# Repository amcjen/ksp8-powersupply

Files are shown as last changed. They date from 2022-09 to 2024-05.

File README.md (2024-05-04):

# ksp8-powersupply
A replacement power supply PCB for the Kurzweil KSP8

Fbf42NQUUAAcW0R

Fbf42NQUEAM9DEA

Fbf42NTVUAAd-vw

Really simple drop-in replacement for the ancient power supply that comes with the KSP8. Included are the v9.0 compatible Eagle
.sch and .brd files, as well as the raw gerbers. The zip file has all the gerbers compressed, and you can usually upload the zip
file directly to most board houses for manufacture.

If you start hearing whining from the power supply transformer, or your unit begins resetting randomly, then it's probably the
power supply, and it's probably time to replace it.

Luckily the great people at Traco make super simple drop-in power supply modules. This board simply adds the right layout, the
proper fuses, and mimic's the power-good circuit that the KSP8 expects to see (though in reality it's likely not even necessary).

The new power supply input specs are super wide, so should be usable pretty much anywhere in the world:

Voltage input:
*90-240V VAC, 47-440 Hz*

Do of course be extremely careful with the mains power coming into this! There are several exposed leads and test points.

Regardless, most of the instructions are on the back of the board, on the silkscreen. It's reproduced here for reference:

### Jumpers
- JP1 - Tie mains gnd to 5V DC gnd (default: connected)
- JP2 - Tie /pwr_ok to voltage supervisor output (default: connected)
- JP3 - Tie /pwr_ok to 5V DC gnd (default: disconnected)

### To run with the power supervisor (default)
- Place U3 and R1
- Leave JP2 uncut
- Leave JP3 open

### To run without the power supervisor
- Exclude U3 and R1
- Cut JP2
- Solder JP3

### Required Components
- U1 - Traco TML-40105 - 5V/8A output
- U2 - Traco TML-40215 - +15V/1.3A / -15V/1.3A
- U3 - Microchip MIC810LUY power supervisor
- F1/F2 - Littelfuse 05200101Z - 1.6A slow blow 5x20mm 250V fuses
- R1 - 100k 1206 resistor

You can buy Tracos at several retailers, like Mouser and Digikey. Yes, they're pricey, but they are also medical grade, have
excellent electrical specs and clean power, and have something like a 70 year mean time between failure (MTBF). So these should
definitely outlast the device (or at least the LCD!)

One last wonderful side benefit is that these supplies seem to run pretty cool, so no need to have that loud fan running anymore.
Feel free to unplug it from the front board for a more silent studio environment.

✨ Happy music making! ✨

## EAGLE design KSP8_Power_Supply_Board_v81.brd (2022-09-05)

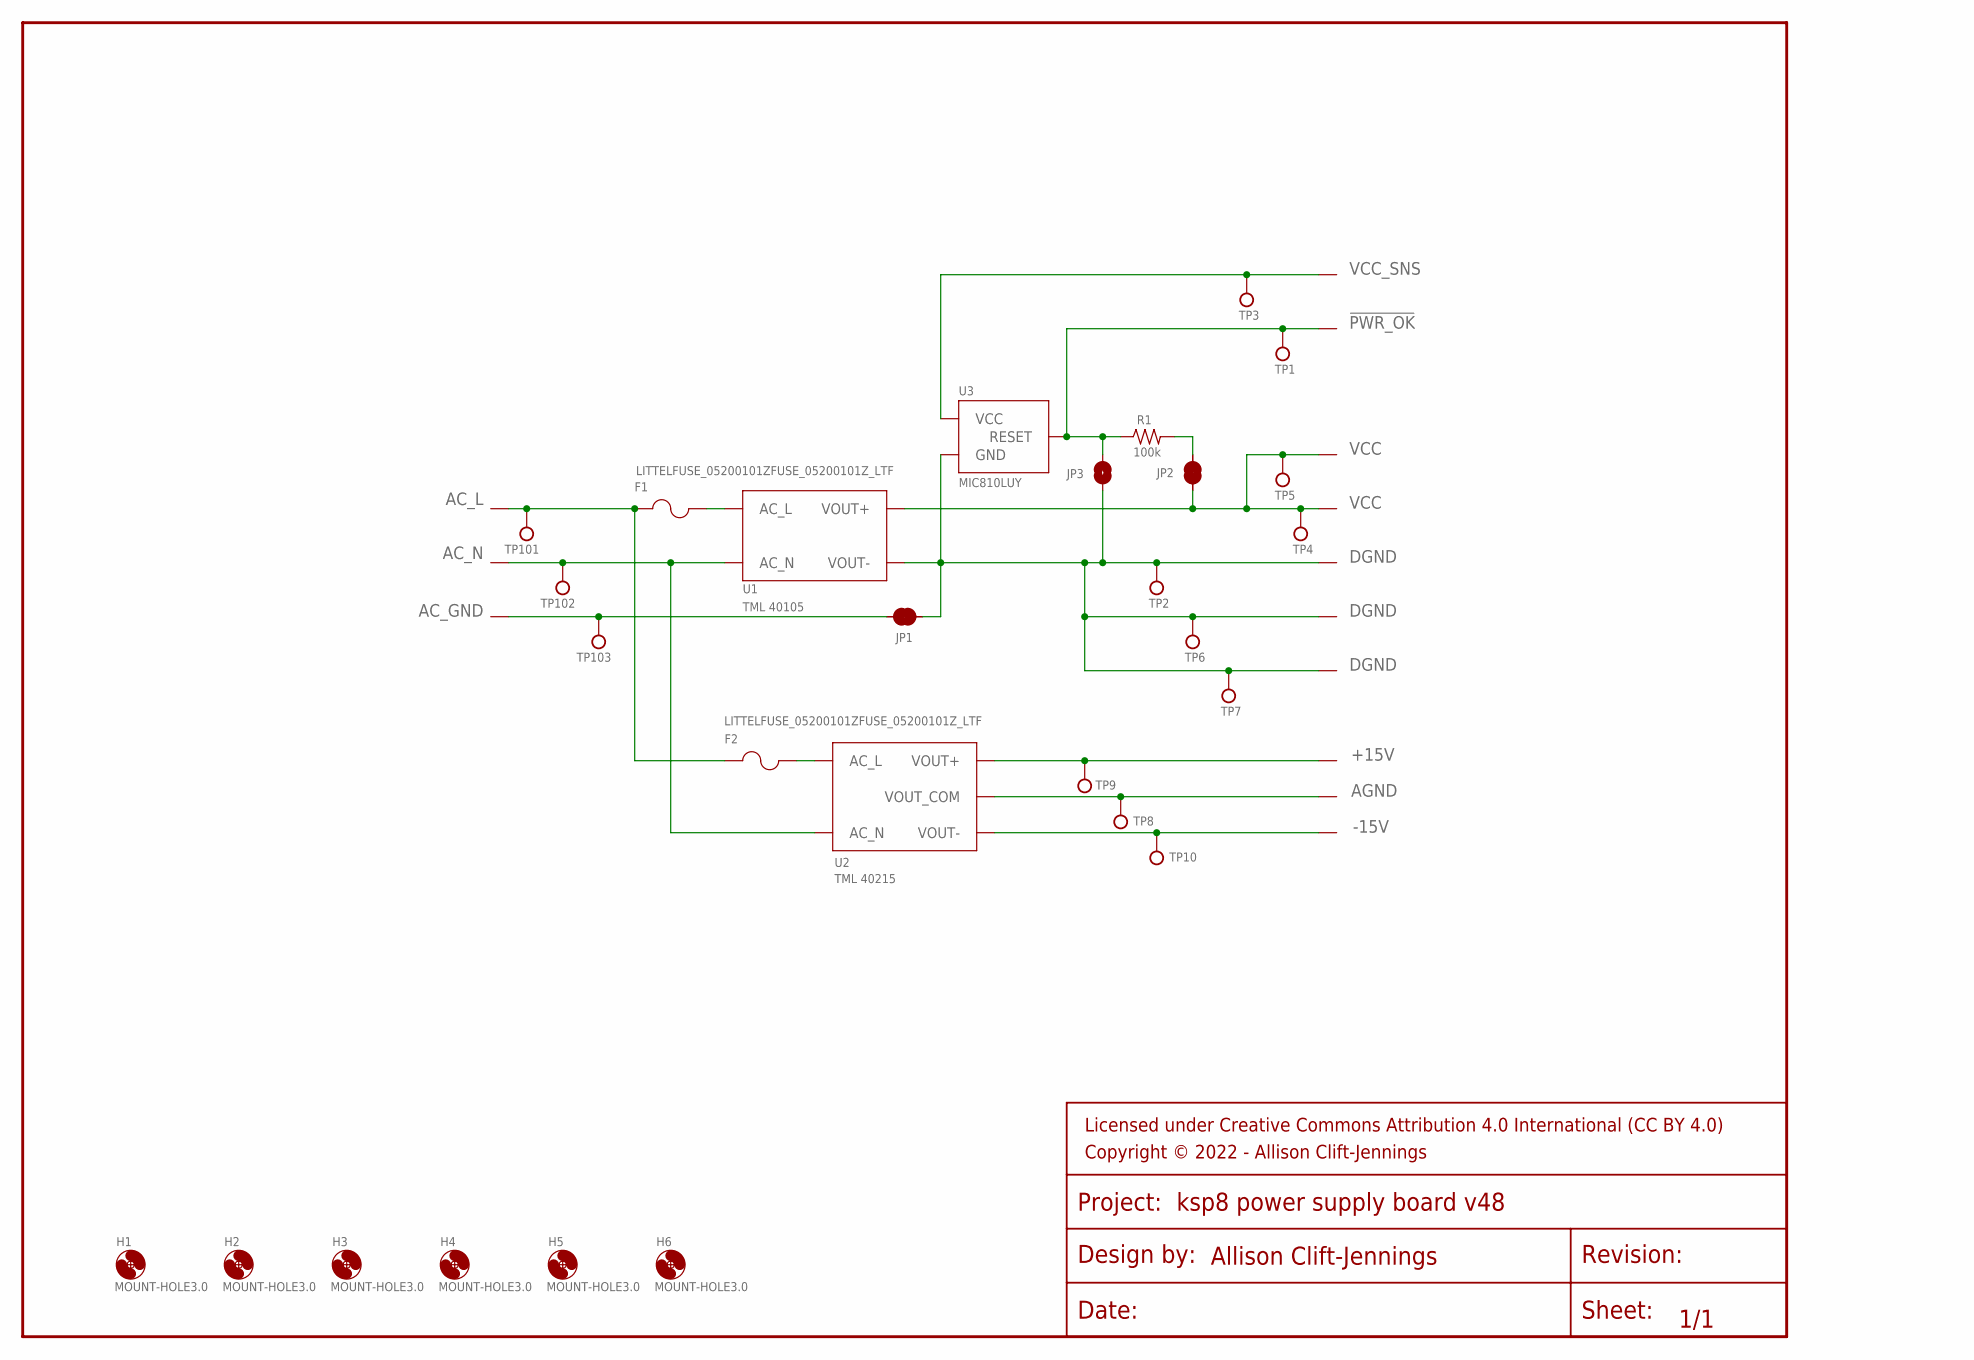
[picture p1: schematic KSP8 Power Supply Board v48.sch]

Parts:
AGND: PADPAD-070-LOOP; PAD-067-LOOP
F1, F2: LITTELFUSE_05200101ZFUSE_05200101Z_LTF; LITTELFUSE_05200101Z_LTF
FRAME1: FRAME-LETTER-OS; CREATIVE_COMMONS
H1, H2, H3, H4, H5, H6: MOUNT-HOLE3.0; 3,0
JP1: JUMPER-SMT_2_NO_SILK; SMT-JUMPER_2_NC_TRACE_SILK_HC
JP2: JUMPER-SMT_2_NC_TRACE_SILK; SMT-JUMPER_2_NC_TRACE_SILK
JP3: JUMPER-SMT_2_NO_SILK; SMT-JUMPER_2_NO_SILK
R1: 100k; 1206
TP1, TP2, TP3, TP4, TP5, TP6, TP7, TP8, TP9, TP10, TP101, TP102, TP103: TESTPOINT; PAD-100-RND
U1: TML 40105; TRACO_TML
U2: TML 40215; TRACO_TML
U3: MIC810LUY; SOT23
U$4, U$5, U$6, U$7, U$8, U$9, U$10, U$11, U$12, U$13, U$14, U$15: PADPAD-070-LOOP; PAD-067-LOOP

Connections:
!PWR_OK: JP3.2, R1.1, TP1.P$1, U3.2 (RESET), U$8.P$1
+15V: TP9.P$1, U2.P$4 (VOUT+), U$6.P$1
-15V: TP10.P$1, U2.P$8 (VOUT-), U$7.P$1
AC_GND: JP1.1, TP103.P$1, U$11.P$1
AC_L: F1.1, F2.1, TP101.P$1, U$4.P$1
AC_N: TP102.P$1, U1.P$3 (AC_N), U2.P$3 (AC_N), U$5.P$1
AGND: AGND.P$1, TP8.P$1, U2.P$6 (VOUT_COM)
DGND: JP1.2, JP3.1, TP2.P$1, TP6.P$1, TP7.P$1, U1.P$6 (VOUT-), U3.1 (GND), U$10.P$1, U$13.P$1, U$14.P$1
unnamed: F1.2, U1.P$2 (AC_L)
unnamed: F2.2, U2.P$2 (AC_L)
unnamed: JP2.1, R1.2
VCC: JP2.2, TP4.P$1, TP5.P$1, U1.P$4 (VOUT+), U$9.P$1, U$15.P$1
VCC_SNS: TP3.P$1, U3.3 (VCC), U$12.P$1

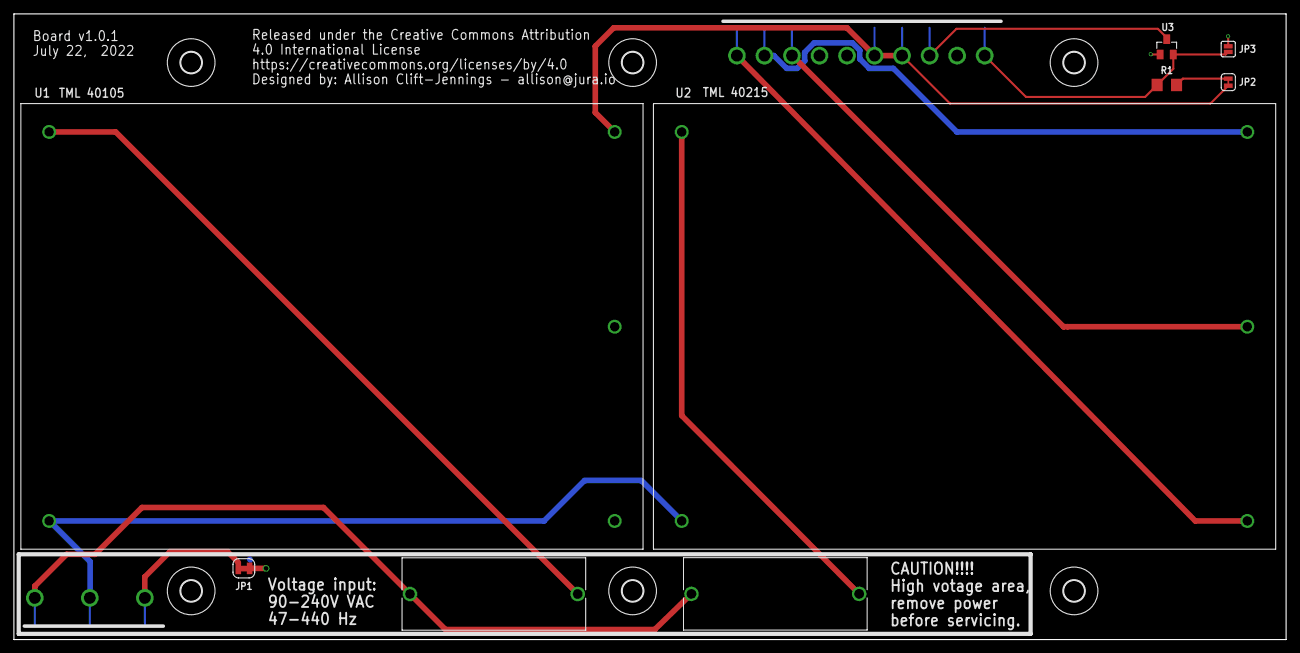
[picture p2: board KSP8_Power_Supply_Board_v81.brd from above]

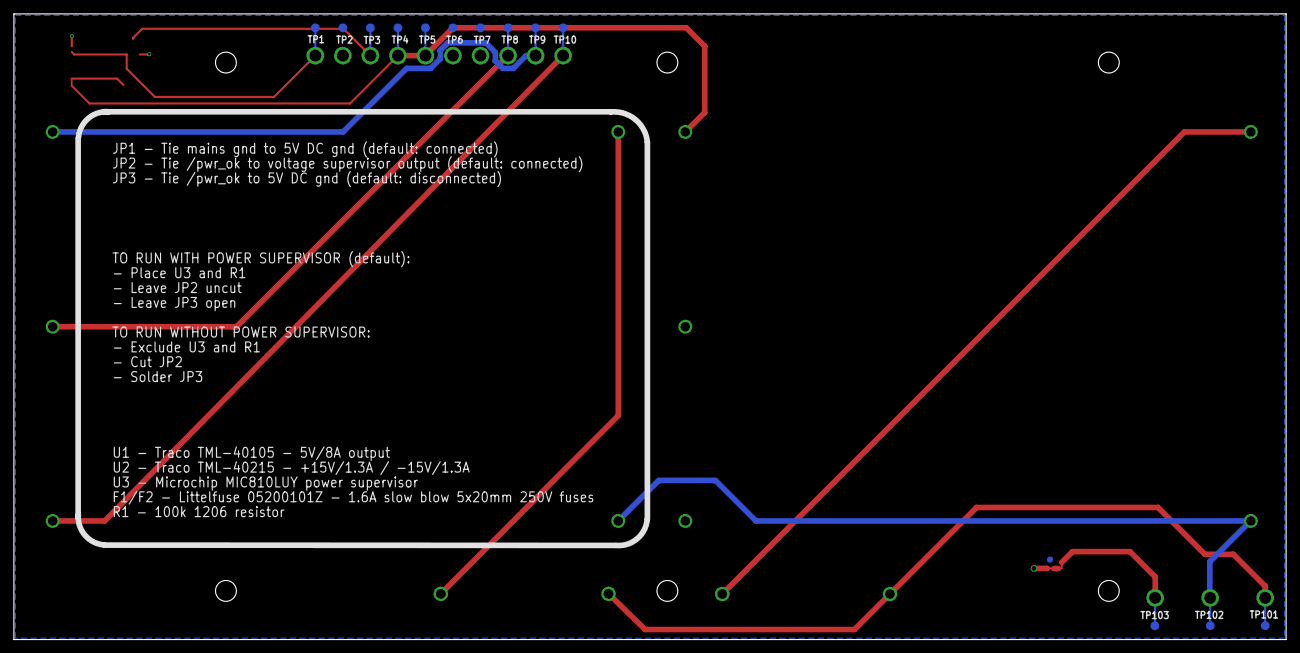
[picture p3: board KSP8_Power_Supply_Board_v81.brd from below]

Board: 2 copper layers, 183.0 x 90.0 mm, 42 parts (13 on the bottom side), 13 nets.

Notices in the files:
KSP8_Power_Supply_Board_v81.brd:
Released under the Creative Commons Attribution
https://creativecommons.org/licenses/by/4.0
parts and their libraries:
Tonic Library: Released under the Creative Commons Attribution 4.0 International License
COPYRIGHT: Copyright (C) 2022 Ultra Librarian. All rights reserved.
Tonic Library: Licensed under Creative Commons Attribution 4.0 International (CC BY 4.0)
